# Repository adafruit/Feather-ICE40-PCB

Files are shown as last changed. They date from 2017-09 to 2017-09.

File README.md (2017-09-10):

# Feather ICE40 #
This is a Feather board featuring an ICE40 FPGA. It can either be used as a soft core CPU or for dedicated logic.

## Contributing ##
Please note that this project is released with a [Contributor Code of Conduct](CODE_OF_CONDUCT.md). By participating in this project you agree to abide by its terms.

### Setup ###
Components and footprints for PCB parts are not included in this repository. Instead, checkout the [adafruit/kicad-libs](https://github.com/adafruit/kicad-libs) repository in the same directory that this repository is checked out in. All part definitions should be relative so that they will load correctly.

### Pull requests ###
For fixes please submit a pull request to the original repository.

### Derivatives ###
If developing your own version of the Feather ICE40 please remove all Chickadee Tech and Adafruit trademarks and follow the [CC-BY license](LICENSE). While not required, please consider open sourcing your modifications so others can learn from your improvements.

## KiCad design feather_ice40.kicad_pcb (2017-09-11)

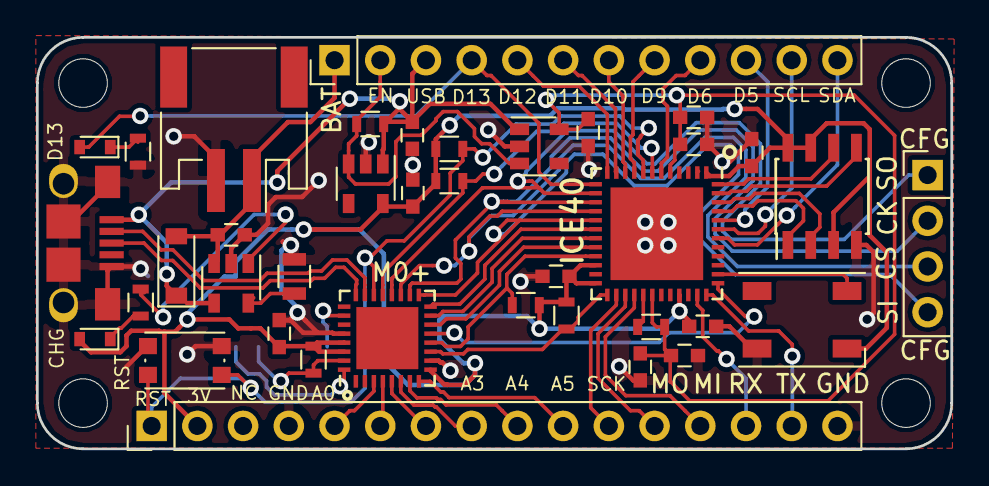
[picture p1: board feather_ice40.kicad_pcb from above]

Board: 2 copper layers, 50.8 x 22.9 mm, 43 parts (1 on the bottom side), 53 nets.

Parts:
C1, C2, C4, C5, C8: 0.1uF; C_0603
C6, C14, C16, C19, C20: 10uF; C_0603
C7, C18: 1uF; C_0603
D1: MBR120; D_SOD-123
D2: Yellow; D_0603
D3: Red; D_0603
D4: Neopixel_THT; LED_WS2812B-PLCC4
J1: USB_OTG; Mini-USB-B-OshPark
J2: CONN_01X02; JST_PH_S2B-PH-SM4-TB_02x2.00mm_Angled
J3, J4, J5, J6: CONN_01X01; MountingHole_2.7mm_M2.5
J7: CONN_02X05; Pin_Header_Straight_2x05_Pitch1.27mm_SMD
J8: Conn_01x04; Pin_Header_Straight_1x04_Pitch2.54mm
J9: FeatherBottom; Pin_Header_Straight_1x16_Pitch2.54mm
J10: FeatherTop; Pin_Header_Straight_1x12_Pitch2.54mm
R1, R3: 10k; R_0603
R2: 100; R_0603
R4: 100k; R_0603
R5, R8, R10: 1k; R_0603
R6, R7: 4.7k; R_0603
R9: 10k; R_0805
SW1: SW_SPST; SW_SPST_KMR2
U1: ICE40UP5K-SG48; QFN-48-1EP_7x7mm_Pitch0.5mm
U2: IS25LPXXX; SOIC-8_3.9x4.9mm_Pitch1.27mm
U3: SPX3819M5-L-3-3/TR; SOT-23-5
U4: SPX3819M5-L-1-2/TR; SOT-23-5
U5: SAMD21E; QFN-32-1EP_5x5mm_Pitch0.5mm
U6: MCP73831; SOT-23-5

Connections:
+1V2: C5.1, C6.1, C7.1, C8.1, C16.1, R2.1, U1.5, U1.30, U4.5
+3V3: C1.1, C2.1, C4.1, C14.1, C18.2, D2.2, D4.3, J7.1, J9.2, R1.1, R3.1, R6.1, R7.1, R10.1, U1.1, U1.22, U1.24, U1.33, U2.3, U2.7, U2.8, U3.5, U5.9, U5.29, U5.30
+5V: C19.1, D1.1, J1.1, J10.3, R4.1, U3.1, U4.1, U6.4
+BATT: C20.1, D1.2, J2.1, J10.1, U6.3
/A0: J9.5, U5.3
/A1: J9.6, U5.4
/A2: J9.7, U5.5
/A3: J9.8, U5.6
/A4: J9.9, U5.7
/A5: J9.10, U5.8
/CHARGE: R5.2, U6.1
/D5: J10.10, U1.44
/D6: J10.9, U1.6
/D9: J10.8, U1.9
/D10: J10.7, U1.10
/D11: J10.6, U1.11
/D12: J10.5, U1.12
/D13: D3.2, J10.4, U1.13
/EN: J10.2, R4.2, U3.3, U4.3
/GCLK4: U1.37, U5.13
/GCLK5: U1.20, U5.14
/M0RX: U1.18, U5.16
/M0TX: U1.19, U5.15
/M0_RST: J7.10, U5.26
/M0_SWCLK: J7.4, R10.2, U5.31
/M0_SWDIO: J7.2, U5.32
/NEOPIX: D4.4, U1.38
/USB_D+: J1.3, U5.24
/USB_D-: J1.2, U5.23
/cdone: R3.2, U1.7, U5.21
/configMISO: J8.1, U1.14, U5.20
/configMOSI: J8.4, U1.17, U5.17
/configSCK: J8.2, U1.15, U5.18
/configSS: J8.3, U1.16, U5.19
/flashMISO: U1.46, U2.2
/flashMOSI: U1.47, U2.5
/flashSCK: U1.48, U2.6
/flashSS: U1.45, U2.1
/iceMISO: J9.13, U1.28
/iceMOSI: J9.12, U1.27
/iceRX: J9.14, U1.35
/iceReset: J9.1, R1.2, SW1.2, U1.8, U5.22
/iceSCK: J9.11, U1.26
/iceSCL: J10.11, U1.43
/iceSDA: J10.12, U1.42
/iceTX: J9.15, U1.36
/sharedSCL: R6.2, U1.21, U5.12
/sharedSDA: R7.2, U1.25, U5.11
GND: C1.2, C2.2, C4.2, C5.2, C6.2, C7.2, C8.2, C14.2, C16.2, C18.1, C19.2, C20.2, D4.2, J1.5, J1.6, J2.2, J7.3, J7.5, J9.4, J9.16, R8.2, R9.2, SW1.1, U1.49, U2.4, U3.2, U4.2, U5.10, U5.28, U6.2
unnamed: D2.1, R5.1
unnamed: D3.1, R8.1
unnamed: R2.2, U1.29
unnamed: R9.1, U6.5

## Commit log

2017-09-10 Original FPGA design with BGA ICE40 8k.
    [feather_ice40.kicad_pcb, feather_ice40.sch, fpga.sch]
2017-09-11 Fully routed. Needs silk cleanup.
    [feather_ice40.kicad_pcb, feather_ice40.sch]
2017-09-11 Silkscreen polish.
    [feather_ice40-B.Cu.gbr, feather_ice40-B.Mask.gbr, feather_ice40-B.Paste.gbr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]
